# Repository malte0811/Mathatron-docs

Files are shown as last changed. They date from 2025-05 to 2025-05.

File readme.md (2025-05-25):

# The Mathatronics Mathatron calculator

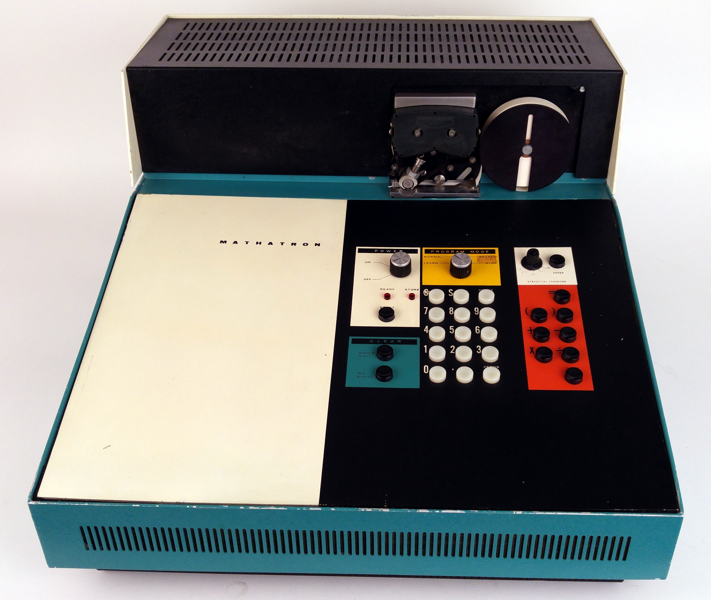
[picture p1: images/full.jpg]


The Mathatronics Mathatron calculator was the first programmable desk calculator, and also one of the first solid state
desk calculators[^1]. First sold in 1963, it was introduced just two years after the Anita Mk 7/8, the first
all-electronic desk calculator. The Anita was essentially an electronic implementation of a comptometer with automatic
multiplication and division. Compared to this, the Mathatron represents a major step forward: It allows expressions to
be entered using standard mathematical notation, including parenthesis, and evaluates them automatically, respecting
operator precedence[^2]. Programs could consist of 24 steps and use 4 number registers (in the original Mathatron 4-24),
and up to 48 steps and 8 registers in the later 4-48 model. Numbers were stored in a (binary-coded decimal!) floating
point format, with 8-9 significant decimal digits in the mantissa.

The history of Mathatronics and the development of the Mathatron calculator has been described in more detail in
multiple places, for example [here](https://www.oldcalculatormuseum.com/c-math8-48m.html) and
[here](http://calcmuseum.classiccmp.org//Mathatron_main.htm). On the other hand, very little technical information is
available: Except for some [patents](./patents.md), the only contemporary sources are some news articles and
advertisements, and I have not been able to find any existing attempt at reverse engineering at least parts of the
machine.

### This repository

In April 2024, I got access to the Mathatron 8-48 owned by the [Arithmeum](https://www.arithmeum.uni-bonn.de/) in
Bonn[^3]. Originally, this was an attempt to get it back to working order. After it slowly became clear that this was
not feasible, I decided to collect my notes in a form that may be useful to owners of other Mathatron calculators. While
some of the information is very technical and unlikely to be of interest to anyone without a Mathatron machine, much of
it is also of general interest as an example of the "lost" ideas used in machines of this era. For example, the [main
memory](./memory.md) consists of a type of magnetic core shift register[^4] that has (to my knowledge) not been used in
any other machines.

Disclaimer: While the Mathatron used in the creation of this repository is owned by the Arithmeum, the Arithmeum has had
no control over the contents of this repository.

### The Mathatron at the Arithmeum

The machine I used for this repository was acquired by the Arithmeum in an auction in 2017. The previous owner had
already done some restorations/repairs on it, for example replacing the main filter capacitors. In some cases, it is not
clear when a repair/change was done, the main reason they stand out as repairs is the newer style of resistor used. The
machine was operational[^5] a few years ago, but broke down repeatedly. Previous breakdowns were apparently easily
fixable (power supply issues), but the most recent breakdown is more complex with most likely at least two faults in the
processor logic.

The machine seems to be a special model manufactured for the [United States Bureau of Medical
Services](https://en.wikipedia.org/wiki/Bureau_of_Medical_Services). Since the BMS was dissolved at the end of the year
1966, this suggests that the machine was manufactured before that date. The official Mathatron model plate has `LKS`
stamped in place of the serial number found on other machines, while the BMS inventory label carries the numbers `62537`
and `#565`. Since these do not match the format used in other Mathatron serial numbers, they are presumably BMS-internal
inventory numbers. `LKS` could either be a generic code indicating a custom-order machine without a serial number, or it
could be a description of the features of the machine. For example, `S` is the type number suffix used for machines with
prewired programs for statistical applications, which is the set of prewired programs present in this machine.

Mathatron plate                  |  BMS plate
:-------------------------------:|:-----------------------------:
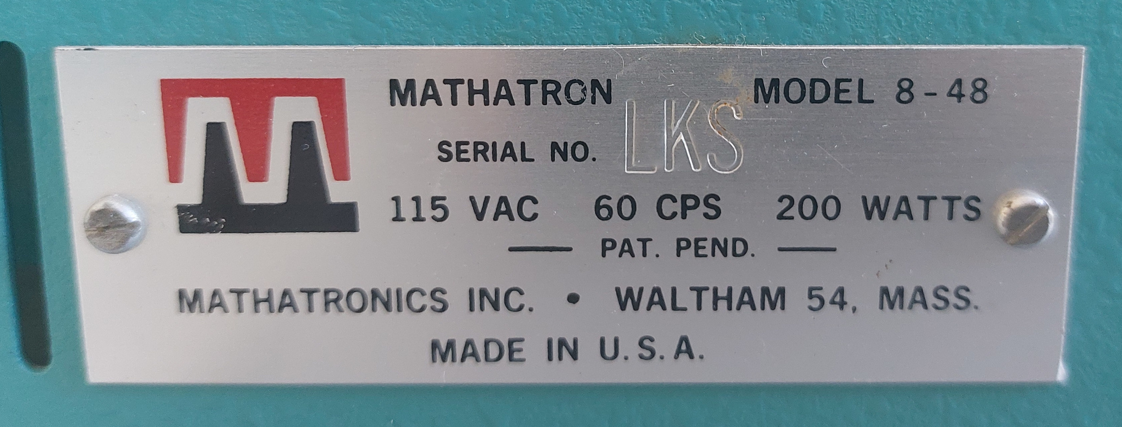
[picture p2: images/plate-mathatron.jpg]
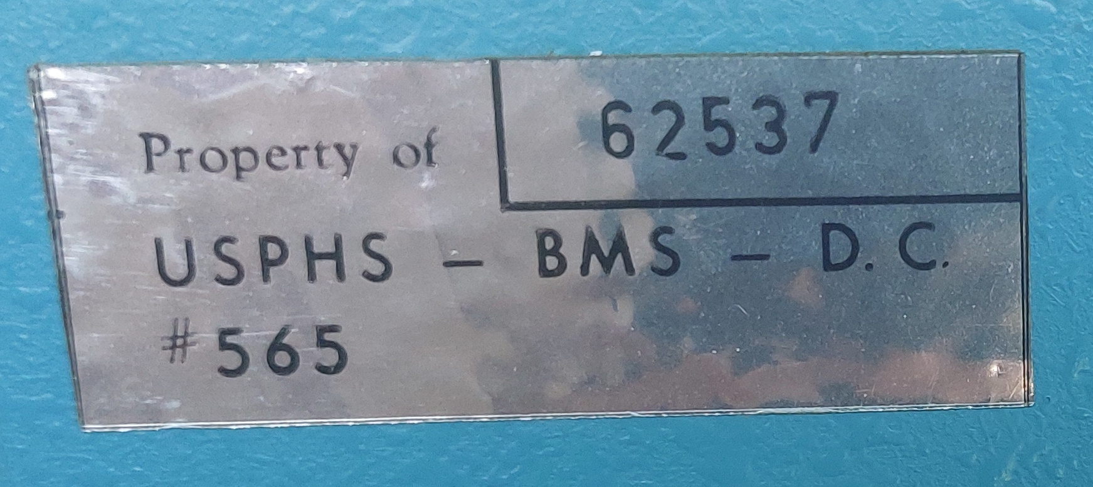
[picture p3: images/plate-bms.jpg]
|  

### Contact

If you have any additional information on the Mathatron, want to ask a question about information not covered in this
repository, or want to suggest a correction, please get in touch with me. You can either [open an
issue](https://github.com/malte0811/Mathatron-docs/issues/new) in this repository, contact me on Discord (`malte0811`),
or by email using either the address listed on my Github account or `schuerks@or.uni-bonn.de`.

[^1]: The Friden EC 130 was developed around the same time, and depending on the cutoff date (first prototype, first
    public demonstration, first sale, etc) the Friden or the Mathatron is first.
[^2]: I.e. `1 + 2 * 3` is evaluated to `7` instead of `9`. In this regard, it is more advanced than modern cheap
    calculators.
[^3]: While I am not technically employed by the Arithmeum, I work at the Research Institute of Discrete Mathematics of
    the university of Bonn, which has close ties to the Arithmeum.
[^4]: Coincident-current core memory is fairly well-known at this point, but there were many attempts of other
    topologies of magnetic core memory. The memory used in the Mathatron is only one example of these.
[^5]: In the sense of being able to evaluate simple expressions. I do not know whether parentheses were tested, and I am
    quite sure that automatic program evaluation was not tested.

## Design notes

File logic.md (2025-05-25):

#### Physical structure

The logic is distributed across 8 PCBs containing 120 PNP transistors each. 4 of these PCBs are accessible when the
machine is opened. The other 4 are installed upside-down below them, making them inaccessible without either removing
the logic unit or opening the bottom of the machine. The top boards are mechanically protected by black plastic plates,
this is not the case for the upside-down boards. The back (solder) side of the boards is accessible by removing 9 screws
on the logic unit (4 corners, 4 sides, 1 in the center).  
Each board is divided into 3 "columns" of 40 transistors each. The columns are labeled `A`-`X` on the board silkscreen.
The structure of each column is symmetric: On the outside are the 100k base bias and 2.2k collector resistors. In the
center area of a column is a matrix with one row per transistor and up to five vertically mounted resistors per row.
Sometimes, this area also contains other components, mostly ceramic capacitors. The transistors[^1] are placed between
the matric and the base/collector resistors on either side. While both the front and back of the boards look very
regular at first glance, differences from the general structure of the traces are rather common.  
The logic unit is connected to the rest of the machine by multiple plugs. 3 plugs contain the data (read/write)
connections to the [core memory](./memory.md), one connects to the keyboard (and an external control interface), and one
connects to "everything else", mostly the power supply, core drivers and printer.

Entire logic unit            |  Single board                  |Reverse side
:---------------------------:|:------------------------------:|:-----------------------------------:
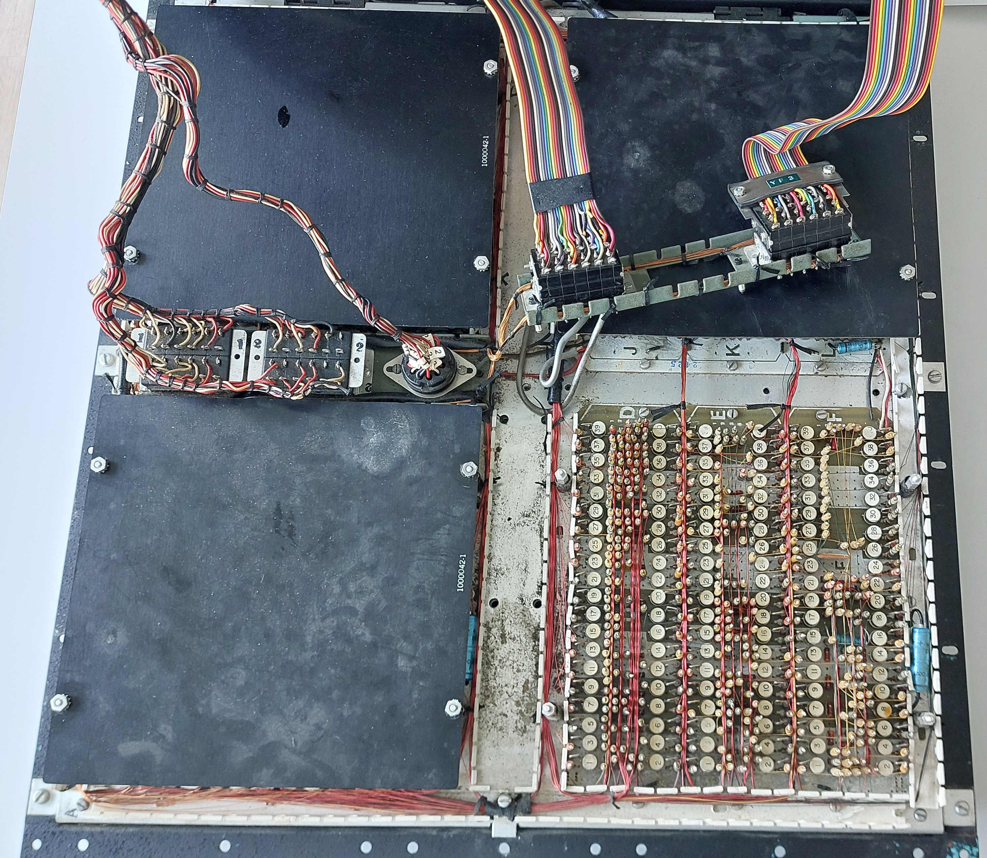
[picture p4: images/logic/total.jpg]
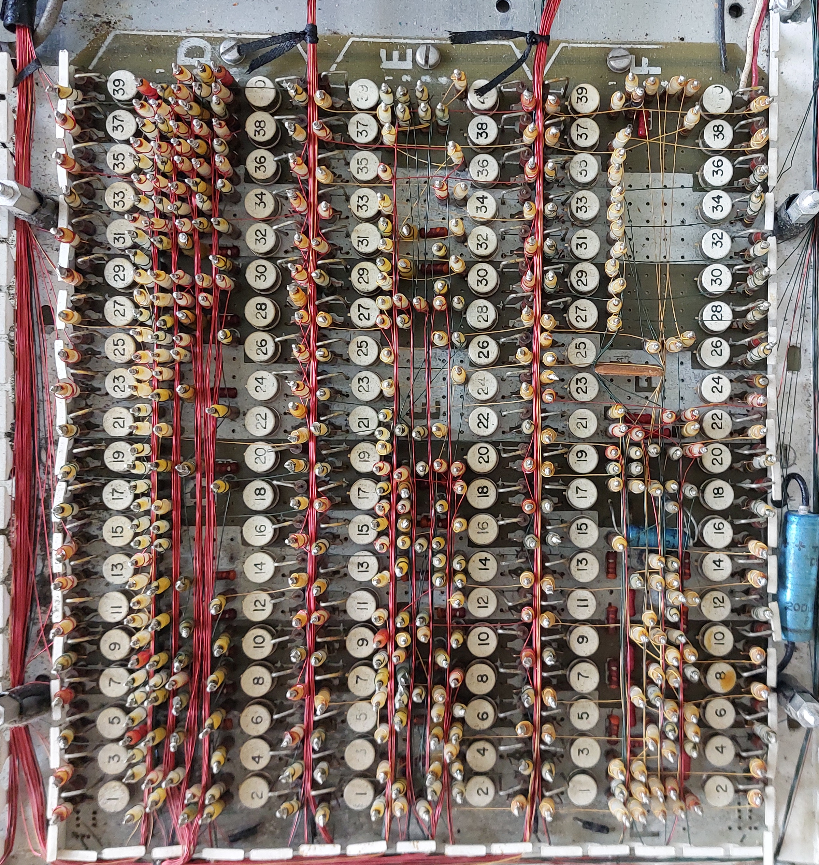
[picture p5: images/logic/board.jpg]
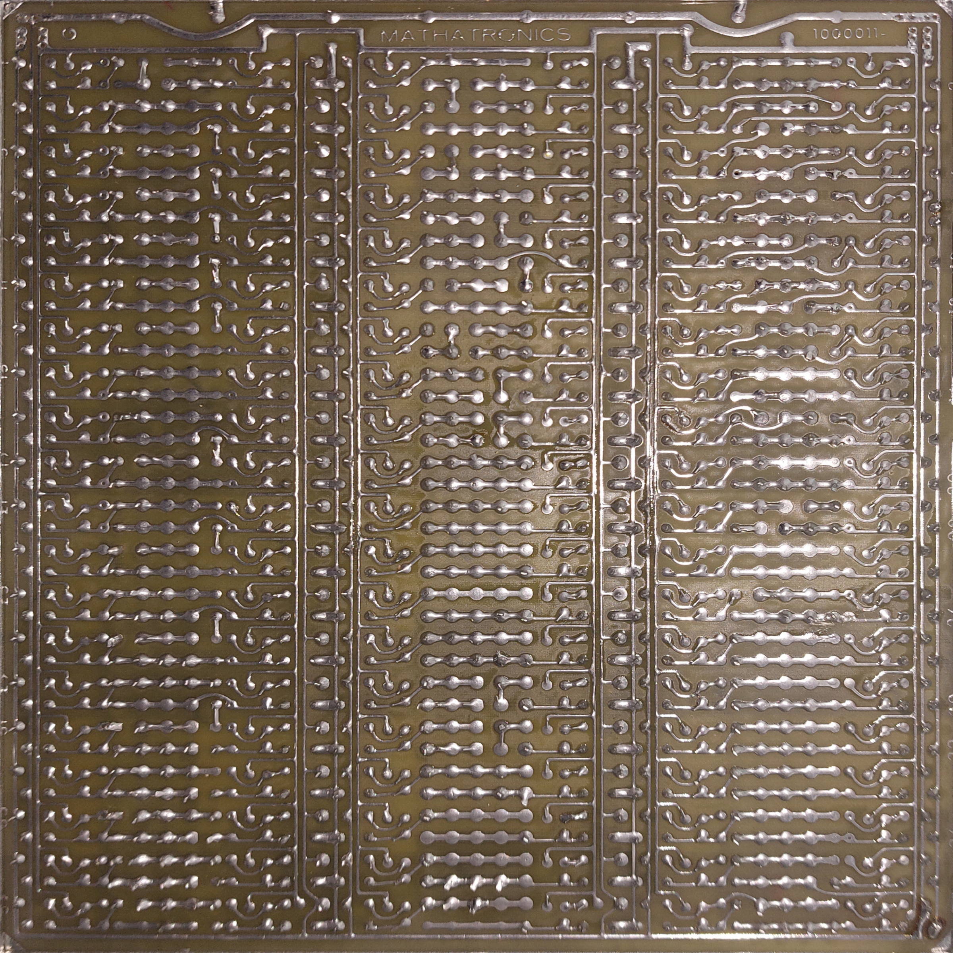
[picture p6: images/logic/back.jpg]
|   |

Only a small fraction of the connections within the logic unit is realized by traces on the PCBs. Instead, the PCBs
contain many vertically mounted resistors. The bottom terminal is connected to a trace on the PCB, while the top contact
is connected to various other similar resistors on the PCB using magnet wire. The magnet wire is connected to the
resistor using a solder joint on top of a [patented](./patents/US3502787-bobbin.pdf) bobbin. Four different colors of
magnet wire are used: "plain" copper, yellow, green, and red. It is likely that the colors have some meaning, either
indicating the type of signal (e.g. control vs data path), or the length of the connection. However, the only color
where I have found a meaning so far are the plain copper wires, which are only used for signals connecting the logic
unit to other parts of the Mathatron through plugs.

Small part of logic unit        |  Magnet wire colors
:------------------------------:|:------------------------------:
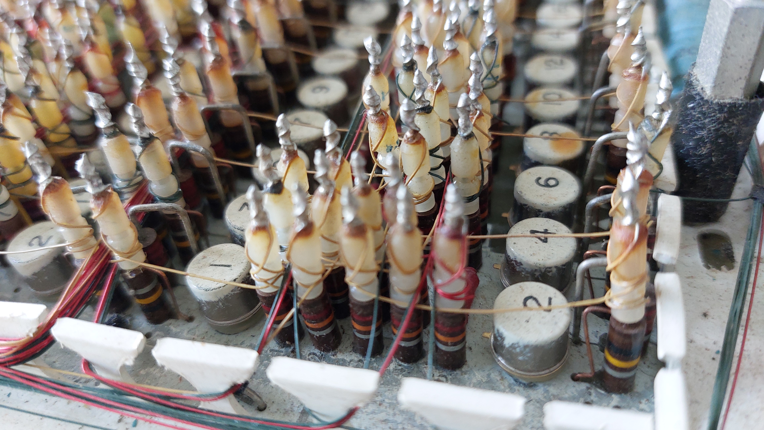
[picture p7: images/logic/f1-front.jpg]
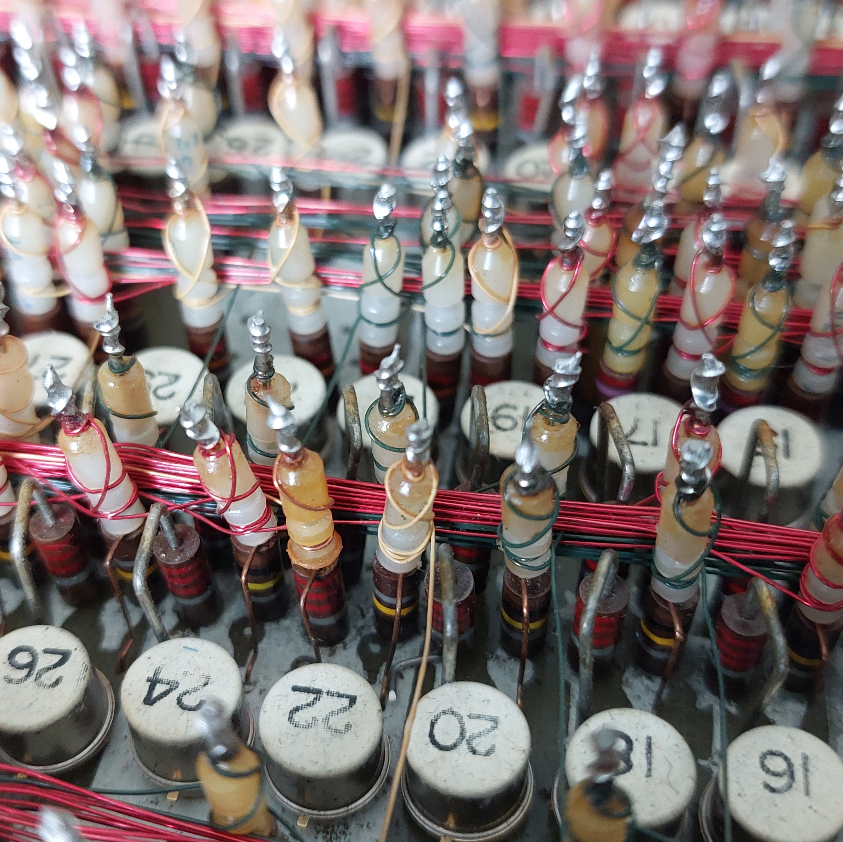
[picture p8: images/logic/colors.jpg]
|   

#### Circuit structure

The logic is primarily constructed from NOR gates, following the schematic below:



Unfortunately, in the physical construction the components of such a NOR gate are not located together. Instead, each
row contains the output stage (100k resistor and everything right of it) of one gate and the input resistors of the
following gates:



This makes it essentially impossible to reliably find all inputs of a gate: The `INT` signals are realized by magnet
wire and essentially impossible to follow. It is not even easily possible to determine whether one has found all input
signals of a gate. Another consequence is that the magnet wire does not contain a signal with sensible logic levels.
Instead, logic signals need to be probed directly at the collector resistor of Q1.

The picture below shows the numbering scheme I use for locations in the logic unit, which probably mostly matches the
one historically used by Mathatronics. The labels always refer to the signal on the top contact of the corresponding
resistor. The base of transistor `T` and the output of the corresponding NOR gate are referred to as `T.B` and `T.C`
(collector). The input resistors of the "next" NOR gate are labeled `T.1` to `T.5`, some of which might not be present.
If some of them are not populated, the indices follow the grid, e.g. only `T.1` and `T.4` might exist for some
transistors. When the column is clear from the context, `T` is simply the painted number on the transistor (`14.3`),
otherwise the column letter is included as a prefix (`F14.3`).

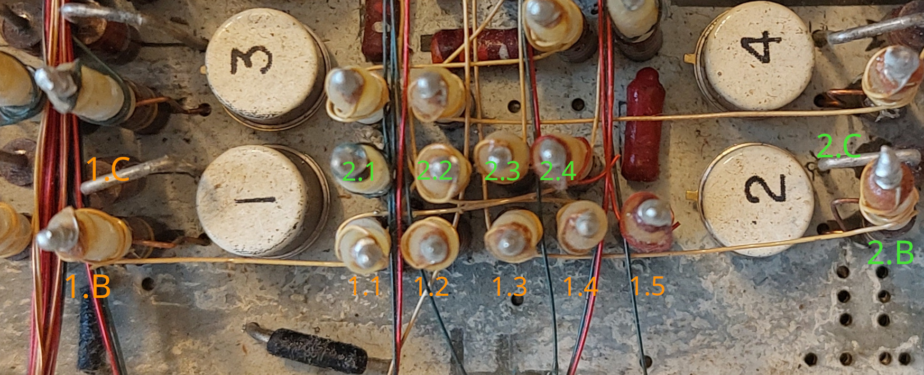
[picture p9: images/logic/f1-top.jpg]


In some cases, the structure deviates from that described above. The simplest deviation is an "AC-coupled input" to a
NOR gate, i.e. an input that is `1` briefly when the previous stage switches from `0` to `1`. This is used e.g. in
counters/T-flip-flops.

#### Reverse engineering

Tracing the magnet wire connections visually (as usually done on PCBs) is essentially impossible for anything more
complex than very short local connections. Instead, everything has to be traced using continuity testing. Continuity
testing runs into two issues.

The first is that the solder joints on top of the resistors are typically sufficiently corroded so that standard
multimeter probes do not make contact. Placing probes on opposite sides of the same joint often does not show
continuity, and applying additional pressure to pierce through the oxide layer with probes is not possible due to the
mechanical construction. The most practical alternative I have found is to always use aligator clips to contact the
solder joints. This is much slower than a quick touch with a multimeter probe, but works very reliably while minimizing
the risk of mechanical damage to the circuit.

The second problem is more interesting: Which connections should be checked for continuity? For those parts of the
boards following the standard row/NOR layout, there is a good answer: The top contact of a "center" resistor should be
connected to exactly one base resistor. Most connections are likely to be "short"/"local", so it is reasonable to start
by looking for connections within a column. This can be done in 1-2 hours per column by checking for continuity from
each "center" resistor to each base connection using the same wire color in the same column. This information can then
be used, together with any "special" PCB structures in the column, to obtain an incomplete list of inputs to each NOR
gate, and a list of outputs to unknown other gates. It is also possible to generate a SPICE netlist to verify
behavior.  
For some columns, e.g. [column `F`](./printer-logic.md), this is enough to follow most of the logic. For other columns,
e.g. `D` and `E`, it does not give much useful information. These columns contain many rows not following the usual
structure, and also many NOR gates with (presumably) inputs from other columns. They also do not contain any connections
to known external signals[^2]. I have not found a reasonable way to trace these inter-column connections yet. I also do
not know how to trace efficiently trace connections in areas that do not follow the usual row structure, and therefore
are not necessarily connected to a base resistor.

#### Utilities and files

The data for the columns I have measured and some utility scripts can be found in [`logic-data`](./logic-data). The
scripts operate on the data for a single columns, which is a directory with the following files. `column-f` is the most
complete example of these files.
- `nets.txt`: This encodes the main connectivity information. Each line has the form `<dotname> <base>`. `dotname` is a
    reference to one of the resistors in the "grid" of the column (e.g. `14.4`). `base` is the index of the BJT to whose
    base this signal is connected (e.g. `3`). For grid positions where a resistor is present, but the base it connects
    to is unknown, `base` is replaced by `?<color>`, e.g. `?green`. The color refers to the magnet wire connected to the
    resistor. If no resistor is present in a grid position, the line is omitted from the file.
- `names.txt`: This files indicates known names for signals, for easier analysis. Each line has the form `<id>=<name>`.
    E.g. `13=bit4` indicates that the collector signal of transistor 13 should be called `bit4`.
- `special-ccs.txt`: This file encodes regions where the traces on the circuit board deviate from the usual row pattern.
    Each row specifies to one connected component, by listing all grid positions that are part of this component as a
    space-separated list. If the last entry of this list is a grid position, the name for the connected component will
    be generated automatically. If the name has the form `base(i)`, the grid positions will be considered as connected
    to the base of transistor `i`. Otherwise, the last entry will be used as the name for the component directly.
- `components.json`: This file lists any additional components placed in the column (primarily capacitors). The file
    should be an array of JSON objects, each of which encodes one "type" of component (e.g. 33 nF capacitors). These
    objects should contain 3 entries:
  - `namePrefix`: The name for the components will be this string followed by an index. This also indicates the
      component type to SPICE.
  - `connections`: An array of array of strings. Each entry of the outer array lists the pin positions of one "instance"
      of the component type, using grid position notation.
  - `lineSuffix`: Any additional information that should be added to the line in a SPICE file. E.g. the capacitence
      value of a capacitor.

[^1]: All transistors are  germanium PNP transistors. The exact transistor model may have varied between different
    Mathatron machines: Some sources, both contemporary and modern, claim that 2N404 were used. On the other hand, both
    the Arithmeum machine and the machine shown
    [here](https://neuron.eng.wayne.edu/auth/Calculators/Mathatron%208-48%20Hassoun/) use Texas Instruments GA2464
    transistors, for which I have not been able to find a datasheet.
[^2]: Column `F` connects to the [printer position sensor](./printer.md), which gives a clear entry point for
    understanding the purpose of the logic.

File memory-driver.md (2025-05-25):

The core drivers can be divided into roughly 3 sections: Those at a positive voltage relative to the core windings
("top"), those at a negative voltage relative to them ("bottom"), and the parts that cross from top to bottom. These
include the core windings themselves, but also some other "side" circuits. The most positive voltage is around 40V,
while the most negative is -10V. At a high level, the top section connects the correct drive lines to +40V. The other
end of the drive lines are connected to one of three constant current sinks in the bottom section, one for the main
drive and one for each of the two copies of the auxiliary driver. The additional side circuits ensure that the current
is at the drive current even between pulses, presumably to reduce supply voltage variation.

### Top side

The top side is formed by the "15-BJT-board" (see [construction](./construction.md)). The top row of PNP BJTs (2N1906)
select the main drive line, while the lower two rows (2N1905) correspond to the two copies of the auxiliary driver[^1].
In addition to the BJTs, there are various components mounted on the back of the board, as well as 10 small pulse
transformers in the bottom edge of the board. The 3 transistors arranged as a column correspond to the same "phase" of
the core driver. The first pulse is in the rightmost column, then the columns are activated one by one from left to
right.  
A pulse on one of the five shift lines is triggered by pulling a logic-level input (0 to -10V) low for 10µs, the
duration of a pulse on the main driver. The logic input is connected to the base of the corresponding main drive PNP
through a 1µF electrolytic capacitor, used to obtain a pulse relative to the 40V emitter voltage instead of 0V. Before
the collector wire enters the memory core, it passes through four pulse transformers at the edge of the board (single
turn each). Two of these cause the corresponding auxiliary drive transistors to turn on. After about 6 µs, the cores of
these transformers saturate, ending the auxiliary pulses[^2]. The windings in the other two transformers (the ones used
to drive BJTs during the previous pulse) are polarized such that they do not turn on the connected PNP transistors, they
only serve to reset the magnetization state of the cores. The order of the transformers along the board edge matches the
BJT columns.  
Some of the auxiliary drive transistors have a low-value resistor (3.9 Ohms in parallel with 6.81 Ohms) connected in
series with the drive transformer. There does not seem to be a pattern to which of them have the resistor and which ones
do not. I suspect that the resistor is supposed to be present for either all of them or one of the two rows, but that
this was accidentally changed in an earlier attempted repair on the Arithmeum machine: Some of these precisely-chosen
resistors are connected between DC rails, and they use a newer style of resistor than the rest of the machine.

Front                        |  Back                         |Transformers
:---------------------------:|:-----------------------------:|:-----------------------------------:
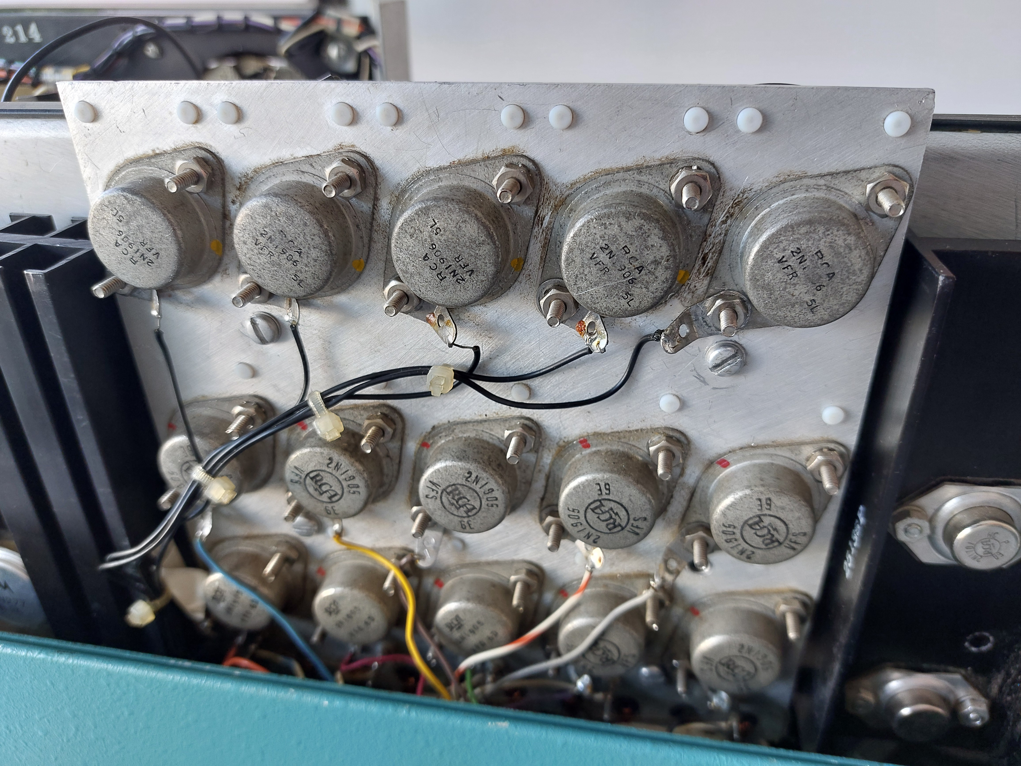
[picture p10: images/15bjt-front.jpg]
|   |

### Bottom side

The bottom side of each of the three drivers (one main, two auxiliary) consists of a simple switched current sink as
shown below. Before the start of an operation (i.e. after a button is pressed), `Enable` switches from -10V to 0V. The
voltage at the upper end of the resistor will be roughly one diode drop below 0V, essentially independent of the voltage
at the input (collector of Q1). This results in a roughly constant current through the resistor, and hence also a
constant current at the input.  
For the two auxiliary drivers, Q1 is one of the 2N1701 (smaller package) on the right heatsink. The current setting
resistors are in the top left corner of the "mixed board" and consist of a 15 Ohm resistor in parallel with another
resistor. In the Arithmeum machine this additional resistor is 91 Ohm for one driver and 68 Ohm for the other, so this
was probably used to fine-tune each of the drivers.  
The current sink for the main driver is also split across two transistors and setting resistors, probably due to the
high total current required (1.5A). These are the larger 2N2338 on the same heatsink. The setting resistors are the
variable resistors at the back of the resistor cage. For these current sinks, the base voltage (`Enable`) is not driven
to 0V but to the voltage of the "extra cap cable" (see [power supply section](./power-supply.md)). This corresponds to
roughly -4V, but uses some variety of active regulation.



### Side load

To keep the supply voltage stable, the current draw should be as constant as possible throughout the memory cycle. For
the main driver this is generally fulfilled automatically since the pulse on one phase ends when the pulse on the next
phase starts. For the auxiliary drivers, where the pulses are shorter, this is implemented explicitly using the circuit
below: `Q17` and `I2` represent the current path through the actual core memory, `I1` is the current sink described
above.  
During a memory current pulse, `Q17` is saturated, pulling `Vcenter` close to +40V. As a result, the emitter voltage of
`Q16` is positive and, since the base is connected to ground, no current flows in this path. Since the maximum
emitter-to-base voltage for `2N3053` is 5V, `D6` is used to take up most of the voltage drop[^3].  
Outside of a memory pulse, the current through `Q17` is zero. As a result, `Vcenter` moves to roughly -1.4V,
corresponding to the diode drops across the base/emitter junction of `Q16` and `D6`. The current path is now through
`R24`, `Q16` and `D6`. Most of the voltage drop is across `R24`, a power resistor found in the "resistor cage".



[^1]:  The common datasheet for both transitors can be found
    [here](https://w140.com/tekwiki/images/1/1e/Rca_2n1905_datasheet.pdf).
[^2]: This also implies that modifying the drive current of the main driver will change the pulse duration of the
    auxiliary driver, since the cores will saturate earlier/later.
[^3]: The actual emitter voltage of `Q16` will be determined by the reverse leakages of `D6` and the base/emitter
    junction of `Q16`. The resulting voltage is likely either beyond the 5V rating or very close to it, causing these
    transistors to fail. In the Arithmeum machine, this transistor had failed in both copies of the circuit, though with
    different symptoms.

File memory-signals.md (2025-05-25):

This sections describes the data connections to the core memory. The read and write circuits seem to match those in [the
patent](./patents/US3438011-shift-register.pdf): The write circuit discharges a small capacitor (50 nF) through the
coil, the read circuit consists of an impedance matching stage followed by a simple RS-latch. The RS-latch is somewhat
biased towards the input from the core since this has a lower signal level than a general logic pulse. Some (all?) of
the write circuits are located in column A, the read circuits are likely located on the lower boards.

Write circuit:  
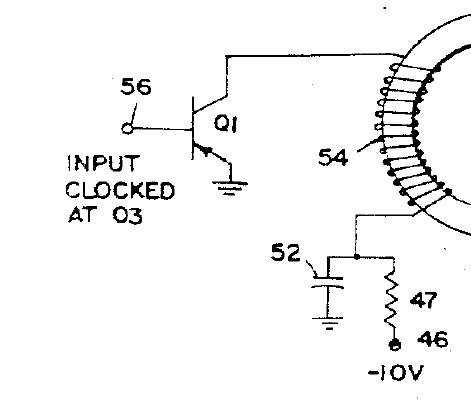
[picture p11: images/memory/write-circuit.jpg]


Read circuit:  
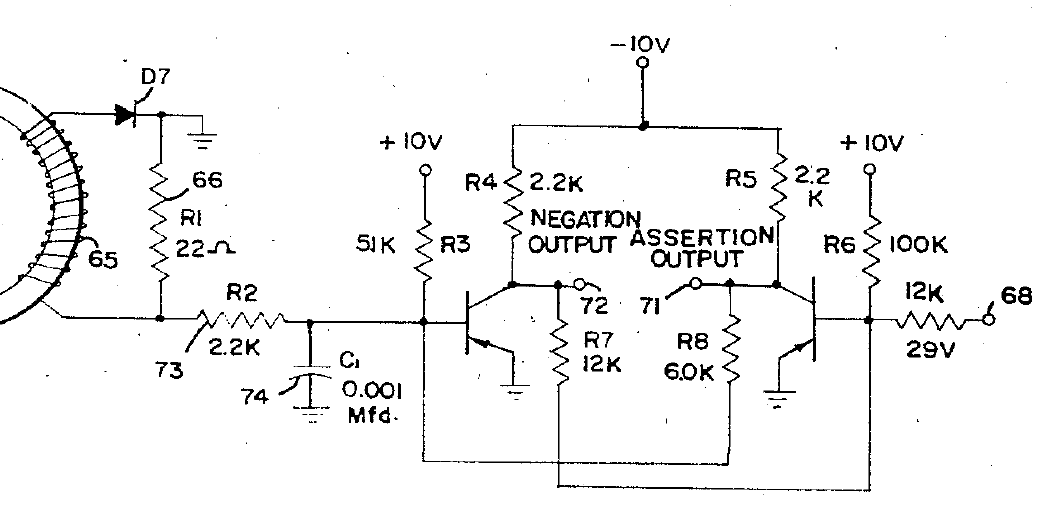
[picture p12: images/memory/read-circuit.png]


#### Connection to the processor

The connectors from the processor to the memory are located on the left half of the logic unit. In the Arithmeum
machine, there are three connectors in total: Two "rectangular" connectors labeled "1" and "2", and an additional "tube
socket" type connector. Most wires on these connectors are red or white, with a few additional black wires.  
The general convention on the rectangular connectors seems to be that black wires are only used for ground connections.
Red wires carry signals coming from the memory (read), and white wires carry signals from the processor to the memory
(write). This also makes sense as an easy-to-remember mnemonic: *red* is *read*, *white* is *write*. There are a few
exceptions to this rule, as some white wires also carry power signals to the "memory interface board". The rectangular
connectors contain a total of 18 red and 20 white wires. Two of the white wires are placed "apart from the rest" and
carry power connections. While the program storage register is logically a 192-bit register, it is most likely
implemented as 4 separate 48-bit registers. This would ensure that shifting all registers 48 times does not affect
memory content. Under this assumption, the 18 read/write pairs correspond exactly to the 14 data registers (A, B, R1-R4,
S1-S8) plus the 4 sub-registers of the program storage register.  
The single black wire on the tube socket also seems to be a ground connection. However, the other wires are most likely
all read connections despite alternating between red and white: There are only 18 capacitors for generating write pulses
on the memory interface board. Additionally, adding additional write points to the memory would be a complex task. On
the other hand, adding additional read points to the memory is simple since the read circuit (without the 22R loading
resistor) presents a high impedence. It would be very hard to implement the algorithms used by the Mathatron without
additional read points, especially 4 bits from the end of the A, B, and R1 registers: These registers are combined
arithmetically, so the processor needs to read a full 4-bit digit from them before having to write the "new" version of
the same digit. The algorithms also make use of shifts to the right, which again require access to the second-to-last
digit.

#### Probing

Both read and write signals can be easily probed on the rectangular connectors. For write signals (white wires), the
"default state" is -10 V, with exponentially decaying pulses to 0V on a timescale of about 10 µs. I am not sure at this
point whether these pulses correspond to logical 1s or logical 0s in the register. A logic analyzer with a threshold of
-5 V gives reasonably clean signals. Read signals (red wires) have much lower signal levels, but can also be probed
without any special considerations on signal integrity: Unlike traditional core memory, this style of core memory
provides a multi-100mV pulse on read outputs.

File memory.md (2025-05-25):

> This section describes the high-level operation of the memory. Details on the main and auxiliary pulse drivers are
> described in the section on [memory drivers](./memory-driver.md), while details of the memory data connections can
> be found under [memory signals](./memory-signals.md).

The Mathatron uses an unusual type of core memory as its main memory described in US patent US3438011: The cores are
used to implement a shift register, or rather multiple shift registers. Data is still stored by the core magnetization
state at one bit per core, but some additional cores are needed to handle the shifting. Additionally, the cores are much
larger than in typical (coincident-current) core memory, with an outer diameter of 6-7 mm. The shift register is divided
into segments of `n` cores along its length (`n=5` for the Mathatron). At all times one of the `n` cores in each segment
is "empty" in the sense that its magnetization state is not part of the memory content. The position of this empty core
is the same in each segment at the same time, and its state always corresponds to a logical 0. A drive "phase" consists
of moving the content of the core before the empty core into the empty core in each segment. After `n` phases, a single
bit is extracted from the shift register.

The picture below shows a 12-bit shift register, using 5 phases like the Mathatron memory. Data is fed into the register
on the left, and read from it on the right. The cores are colored by their phase. At the start, all cores except for the
blue ones contain data bits (letters). A single drive phase moves the contents of the red cores into the blue ones, now
leaving the red cores empty. In the next phase, data is shifted from the yellow cores to the red ones. This phase is
special because the first core of the shift register is red, and the last core is yellow. The contents of the first core
are simply cleared, leaving it available for data to be written to it in one of the following phases[^1]. The contents
of the last core are transfered into a read circuit (essentially a flip-flop), which makes the data bit `M` available to
the processor. After three more drive phases, the last row of the image shows the register in the same state as at the
start, but with all bits shifted by one position to the right.



The shifting is implemented by passing a current through windings[^2] on both the core being shifted from and the core
being shifted into (the "empty" core) at the same time. The pulse through the core being shifted from is known as the
"main" pulse, while the pulse through the core being shifted into is known as the "auxiliary" pulse. Both pulses are
strong enough to flip the magnetic state of the cores, but the auxiliary pulse is only "barely" strong enough. To pass
information from the first core to the second, there is a 5-turn "output winding" on the first core connected to a
single-turn "input winding" on the second core. If the first core flips, a current pulse is induced in the output
winding and through that in the input winding. This pulse is opposed to the auxiliary pulse and it strong enough to
prevent the second core from flipping. If the first core does not flip, no current is induced and the second core flips
from the auxiliary pulse.

To prevent a flip of the second core (in the next phase) from flipping the first core through this output/input winding,
the windings are connected by a diode. The voltage induced in the single-turn input coil by a flip of the second core is
smaller than the forward voltage of the diode, so cannot affect the first core.

The polarity of the main pulse corresponds to setting a core to 0. Since the auxiliary pulse needs to flip the
previously empty (hence logical 0) core if not opposed by the input/output pulse, its polarity sets cores to 1. This
implies that shifting involves an inversion: If the core being shifted from was previously set to 0, it does not flip,
no current is induced, and the empty core is set to 1. If the core being shifted from was previously set to 1, it flips,
induces a current, and prevents the empty core from flipping from its 0 state. For simplicity, this is ignored in the
image above.

In some cases, it is necessary for the logic to have access to the "next" digit in memory: If e.g. two numbers are
added, their last decimal digit would normally shift out of the core memory (bit by bit) during the same period as the
last digit of the result is shifted into the core memory. Since the digits need to be fully known to compute the bits of
the result, this would not be possible with "pure" shift registers. Instead, an additional output measurement coil is
installed on the core 4 bits (5 cores) from the usual output core. This provides the "next" digit to the processor,
allowing it to compute (in the example) the summed digit before it has to entered into memory. In some cases, some cores
are physically missing from a register, presumably for similar reasons.

### Physical construction

The memory is divided into rows of 20 cores each, using the wiring scheme suggested in figure 10 in the patent. Each row
is manufactured as a separate module. In the Mathatron 8-48 at the Arithmeum, there are approximately 40 modules in the
larger section on the back (only partially accessible) and 12 modules in the smaller section at the front. Since the
shift register uses 5 cores for 4 stored bits, each row corresponds to 16 bits and each 48 bit register consists of 3
rows.

The drive wires are threaded through the entire core, with the starting point at the top of the front core section.
Below the core sections, the wires simply pass from each core "column" of the front section into the corresponding
column in the back section. At the top of the back section, the wires are threaded back into the corresponding column of
the next section of the module. Since the direction of the drive wires reverses between sections, the polarity of the
input/output windings of the modules also reverses at each section boundary.

The auxiliary drive is split into two identical copies of the same driver circuit for unknown reasons. The first two
segments of each module are driven by one of these, the remaining two segments are driven by the other. The main drive
is not split in this manner, and drives all segments of all modules.

The main and auxiliary driver circuits are reasonably accessible and described in [this section](./memory-driver.md).
Unfortunately, the data in- and output circuits and especially their connections to the core are not. This makes the
organization of the memory into logical registers a guess. The front section is likely the program storage for both
pre-wired and user-provided programs (see below). The back section probably consists of either 39 or 42 modules,
corresponding to 13 or 14 48-bit registers. This roughly matches the patent: 8 S-registers for user programs, 4
R-registers for handling parathesis, and A and B registers for intermediate results. This corresponds to 14 registers
overall. On the right end, a wire connects the last contacts of every third row. This contact probably corresponds to
the last (or possibly first) bit of a register, where data is inserted/extracted.

Missing cores                        |  Register connections                    |
:-----------------------------------:|:----------------------------------------:|
|   |

#### Pre-wired programs

Mathatron provided multiple "pre-wired" programs with each machine, which allowed common programs to be entered with a
single keypress. This is probably achieved by threading one wire per pre-wired program through the entire program
storage. When a current pulse is applied to this wire, all cores of the program storage are simultaneously set to the
correct value for the respective pre-wired program. I have not been able to confirm this directly, but there are
strong arguments in favor of this theory:
- There is no "large" memory in the machine besides the main core memory (no core rope or similar). The pre-wired
    programs have to be stored somewhere, and a wire passing through all relevant cores provides this storage in a
    cheap and compact form.
- Storing and entering the pre-wired programs in this manner minimizes the amount of extra circuitry needed to support
    them: Entering a program means sending a single current pulse through a wire not used for any other purpose, while
    executing a pre-wired program is indistinguishable from executing a user-provided program and therefore does not
    need any extra hardware. The program selection knob seems to directly select between such wires. The actual
    processor does not have to be modified in any way to support pre-wired programs.
- The front section of the memory has a large amount of "random" thin wires going through it. I do not have access to
    the reverse of the back section of the memory, but the "randomness" of these wires suggests that they may be used to
    implement the programs. Additionally, the memory of the front section (12 rows of 16 bits) corresponds exactly to
    the 192 bits needed to store 48 4-bit program steps.
- The wiring of the selector and the ENTER button for pre-wired programs: The ENTER button is a SPDT switch, that
    normally charges a small electrolytic capacitor (connected to the common contact) through a resistor. When pressed,
    this capacitor is connected to "some wires in the core" through the program selector.
- There is some suggestion that the front section of the memory can be replaced with relatively little work, which
    matches the fact that Mathatronics offered to install pre-wired programs in existing machines.
- The main Mathatron patent (US3996562) mentions that the pre-wired programs (in particular the square root program) are
    stored in the same memory as the user program.

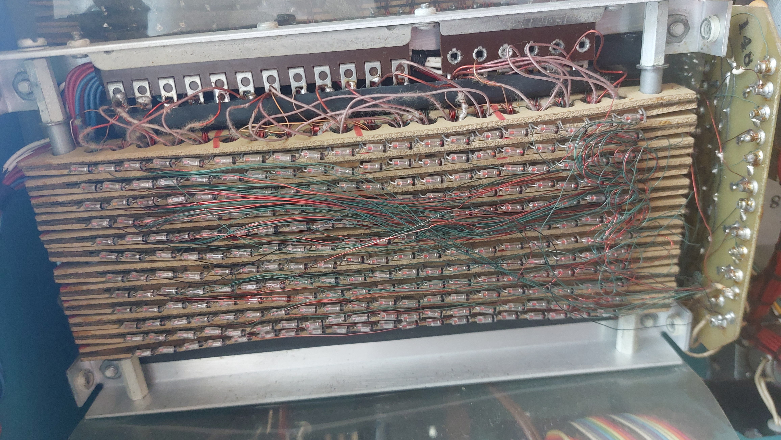
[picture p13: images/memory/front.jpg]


[^1]: It does not matter during which phase the input is written to the core, as long as it happens before the next
    phase shifting from red to blue.
[^2]: These are single-turn windings, using a wire passing straight through all cores of a phase.

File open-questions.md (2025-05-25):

This list contains some strange details I found and was unable to explain, as well as general questions about the
history of Mathatron machines.
- Two parallel resistors in the "resistor cage" dissipate 20W each, for 40W total. There is no forced-air cooling in
    this area, and even without the cover attached the resistors reach 80°C (176°F) within 20 seconds. Both the
    temperature and the total wasted power would suggest that this is not the intended behavior. On the other hand, the
    resistors are Ohmite power resistors rated for operation up to 350°C, so it may be the correct behavior after all.
    There is also another resistor in the resistor cage dissipating multiple Watts, but nowhere near as much as this
    pair.
- Is the -10V rail intended to be at that voltage? In the Arithmeum machine, it seems to be too close to 10V to be
    caused by broken regulation. On the other hand, this would mean that the main logic levels of the machine are -10V
    and 0V. Both the [main Mathatron patent](./patents/US4611307-mathatron-latest.pdf) and some documentation[^1]
    suggest that it should be -5V and 0V.
- What is the correct value, and the purpose, of the large resistor on top of the resistor cage? In the Arithmeum
    machine this is a fixed-value dark green resistor without any markings. In measurements, it shows a very low value,
    but this could also be some other circuitry in parallel with the resistor. In pictures of other machines, this
    resistor seems to be adjustable rather than fixed-value.
- On the right side of the "mixed board", a white/purple striped wire leaves the board and enters a wire harness, only
    to leave the harness a few centimeters later and connect to the board again. The endpoints of the wire are already
    connected by a trace on the board. Was this intended to confuse reverse engineering efforts, or spot direct clones?
    Or is it an artifact from an earlier revision of the machine?
- What is the correct wiring behind the 15-BJT board? In the Arithmeum machine, it appears that this section has been
    modified in some earlier attempted repair/restauration (newer resistor style). Some high-precision resistors are
    placed between DC signals that are also connected by far lower-precision resistors, while some base connections are
    missing series resistors. It seems likely that this was a mistake during the earlier changes.
- The Mathatron at the Arithmeum seems to be a custom model, probably similar to IBMs "Request Price Quotation". How
    does it differ from a normal 8-48S, which seems to be what the customizations are based on?
- What is the full model history of the Mathatron calculator? For example, the [machine owned by Mohamad H.
    Hassoun](./known-machines.md) looks identical to the Arithmeum machine on the outside, but uses a different layout
    of the logic unit and contains an additional board in the top section.

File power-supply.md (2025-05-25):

#### Filter capacitors

The filter capacitors have been replaced in the Arithmeum machine, so this information should be taken with a grain of
salt.  
The left set of capacitors consists of 1000µF capacitors, while the right section uses 3300µF capacitors. With the
exception of the top right capacitor of the left section, all center connections are to ground.

##### Connections in the left section

-45V (A): Used for the printer, rectified by two diodes on the mixed board.

-45V (B): Used for BJT base bias, rectified by a single diode on the mixed board.

+45V (A): Directly after half-wave rectification, not used for anything

+45V (B): After smoothing by a large inductor (transformer-like, inside the main chassis), forming a pi-network with the
capacitors for +45V (A).

+10V: This is primarily used for base bias in the main logic unit. It seems to be derived from +40V (B) by a dropping
resistor, without any regulation.

-10V: This is derived using some sort of regulation from the -18V rails in the right capacitor section. The positive
(inner) end of one of these capacitors is not connected to ground, but to a different net referred to as the "extra cap
cable" in some schematics.



##### Connections in the right section

TODO work out A vs B

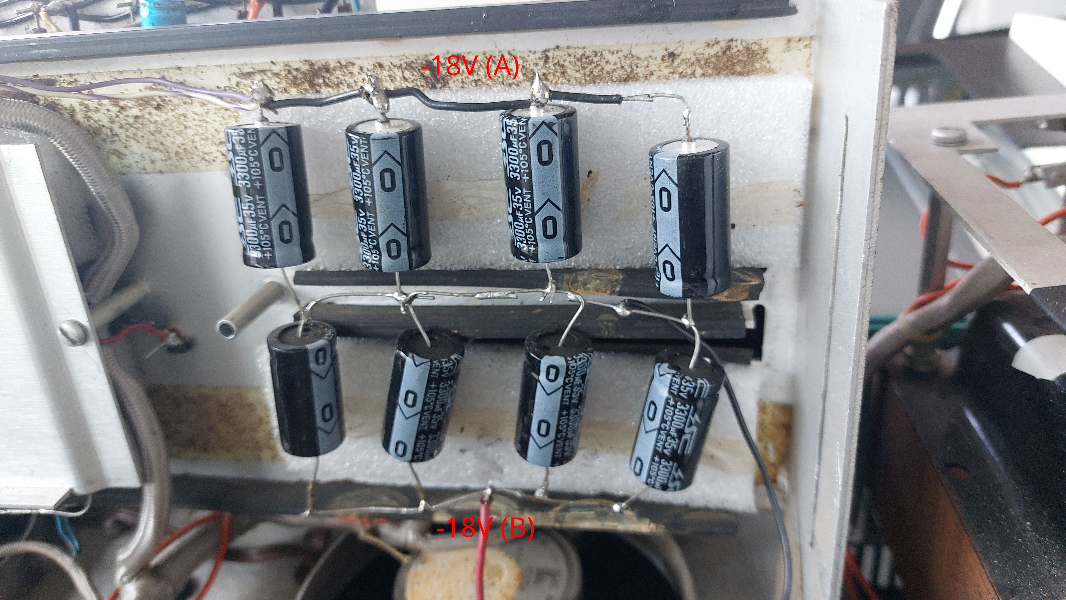
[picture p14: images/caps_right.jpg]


#### Other circuits

The higher-current rails are rectified using stud-mounted diodes in front of the "mixed board". The lower-current rails
use generic axial-lead diodes mounted on the mixed board itself. There are two additional high-power (stud-mounted)
diodes on the mixed board itself. In the Arithmeum machine one of them is mounted on a heatsink, but this appears to be
a late modification: [This](http://www.calcuseum.com/SCRAPBOOK/BITMAP/BONUS/75987/_SMD75990_XL.htm) picture shows the
internals of the same machine before it was acquired by the Arithmeum. The right stud-mounted diode is still mounted
directly to the board, but the board is already discolored around it (indicating high power dissipation). This is
confusing since, from my measurements, this diode should only conduct when the +10V rail drops below 0V. At the same
time, this seems to be a realistic scenario since the original design included a high-power diode. The other high-power
diode prevents the "extra cap cable" from becoming more negative than the -10V rail.

One of the more confusing parts of the Mathatron is (what I assume to be) the regulation circuit of the -10V rail. This
is the main voltage used in the logic unit, so it is at the same time a high-current supply and needs to be reasonably
stable under uneven current (processor activity). However, the regulator "feeds" the -10V rail depending on the voltage
of the "extra cap cable", and tends to reduce the current when the voltage drops rather than increasing it (both in
simulation and measurements). The circuit can be found in the `PSU` sheet of the KiCAD project in the `schematics`
folder. As usual, since this is based on reverse engineering, it is likely to contain mistakes.

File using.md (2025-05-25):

> This section is not based on reverse engineered data from the machine at the Arithmeum, instead it is essentially a
> summary of parts of US patent 4611307.

#### General operation

To use a Mathatron as a basic calculcator, the `PROGRAM MODE` switch has to be set to `NORMAL`[^1]. After turning the
main power switch to `ON`, the `START` key has to be used to prepare the machine for operation. This causes the `READY`
light to come on. After this, the machine can be operated using "normal" (infix) mathematical expressions, e.g. `12 + 17
/  4`. All entered numbers and operators are printed to the paper tape. After each keypress, the `READY` light should
briefly go out before coming back on[^2]. Pressing `=` prints the result of the expression and returns the machine to
"standby" mode (i.e. `START` has to be pressed before the next computation).

- Opening brackets at the start and closing brackets at the end of the expression can be ommited.
- The `ZEROS` button allows the user to use scientific notation: Entering a number `a`, pressing `ZEROS` and entering a
    number `b` corresponds to entering the number `a * 10^b`[^3].

The 8 data registers[^4] are referred to as `S1` to `S8`. To store a value in one of them, enter the value (or a formula
computing the value) and press the `=S` key, followed by the index of the data register. The `STORE` light will come on
while the Mathatron waits for the register index to be entered[^5]. After this, the value can be used in computations by
entering `S` followed by the register index at any point inside the formula. The register contents can also be printed
using `PRINT` followed by the register index.

#### Programming

The Mathatron is programmed by selecting the `LEARN` mode and entering a sequence of equations. These equations will
typically use the `S`-registers for intermediate results and possibly some inputs. To run the program, the `AUTO` button
is used in one of the other modes (`NORMAL`, `BRANCH`, `STOP`). The Mathatron will then essentially simulate the same
sequence of keystrokes used to create the program.  
Every time a constant[^6] is encountered, the program is interrupted and the user is asked to input the correct
value[^7]. This makes programming for "simple" repetitive tasks very intuitive: To compute e.g. the same expression for
every row of a table, it is enough to enter the expression once for the first row while in `LEARN` mode. Afterwards, it
is enough to enter the contents of the table into the calculator, treating `AUTO` as a "next field" key.  The behavior
upon reaching the end of the entered program depends on the selected mode:
1. In `NORMAL` mode, the program continues from the start as an infinite loop.
2. In `STOP` mode, the program will stop after a single execution. It may be necessary to press the `AUTO` button once
   for every unused program step (of 24 or 48) to return to the start of the program, but this may be a mistake in the
   patent.
3. In `BRANCH` mode, the program will be repeated if the last result computed before the end of the program was
   negative. This is primarily intended for iterative numerical methods (e.g. Newton's method), where the last result
   might indicate whether the remaining error is below some set threshold. In this application, no values are entered
   into the program. The `BRANCH` mode can also be used to accumulate some expression over an arbitrary number of input
   values, e.g. computing $\sum_{i = 0}^n x_i^2$.

#### Prewired programs

Each Mathatron calculator comes with a number of "pre-wired" programs. These are commonly used programs that can be used
at the push of a button. The most common example (present in all machines?) is the square-root program, approximating
the square root of the value in register `S1` and storing the result in `S3`. Other programs are available depending on
the type of Mathatron, e.g. `8-48S` machines contain pre-wired programs for various statistical functions. These
pre-wired programs are entered into the same program storage used for user programs. This has two direct consequences
that may not be obvious from general information on the Mathatron:
- Using a pre-wired program automatically erases the current user program.
- Pre-wired programs (including the square-root function) cannot be used as steps in user programs.

#### A note on Turing completeness

It is not entirely clear whether the Mathatron (in `BRANCH` mode) should be considered Turing complete. This question is
of interest since Turing completeness is often a consideration when deciding whether a device should be considered a
computer or a calculator. Clearly, the computation model needs to be generalized to provide arbitrary amounts of memory.
Since there is no indirect addressing, this has to be done by making the memory available in each register infinite
instead of providing an infinite number of registers. There are (at least) two somewhat natural ways to generalize the
floating point values stored in the registers:
1. Registers store rational numbers.
2. Registers store a product of an integer with a power of 10. Here, the exponent cannot be an arbitrary integer, since
   e.g. division by 3 would not have a well-defined result. Instead, the exponent has to have a fixed minimum value.

Intuitively, the important difference between these two approaches is that the second allows access to individual digits
of an integer value `a`: For example, the last (least significant) digit can be accessed using `a - (a / 10^(e - 1)) *
10^(e - 1)`, where `e` is the minimum value of the implicit exponent. The second part of the formula can be interpreted
as shifting `a` to the right and then back such that the least significant digit cannot be expressed in the intermediate
result. This allows a register to be used as an infinite stack (or one side of the tape of a turing machine).

See [On the control power of integer division](https://www.sciencedirect.com/science/article/pii/0304397583901299) for a
full proof that the second model is Turing complete, noting that this number model is equivalent to integers. I am not
aware of a proof that the first model is not Turing complete. Some results from the same paper suggest that it is not,
but they only apply to numbers that can appear as intermediate results after a fixed number of iterations. These values
*can* be computed as the final program output (after a non-constant number of iterations), so this is not enough to
prove incompleteness.

[^1]: `BRANCH` and `STOP` are likely to work as well, but this has not been tested and is not specified in the patent.
[^2]: The `READY` light is extinguished during processor activity. This can cause confusion since there is no external
    way to distinguish between operation and "standby" (`START` not pressed/computation completed).
[^3]: If the patent is accurate, negative values of `b` are not supported.
[^4]: Or 4 in a Mathatron 4-24
[^5]: This light bulb is missing in the Bonn machine, it is not clear when it was removed.
[^6]: A constant is defined as a numerical constant followed by an operator. It is not clear whether `=S` is considered
    an operator in this context.
[^7]: For more complex programs, this is of course a problematic behavior: Such programs are likely to contain constants
    that are not supposed to be modified (e.g. π). The documentation stores these "global" constants in register before
    the program is started, which still seems cumbersome and error-prone.

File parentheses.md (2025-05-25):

> This section is not based on reverse engineered data from the machine at the Arithmeum, instead it is essentially a
> summary of the patent US 4611307.

One of the main selling points of the Mathatron was its capability to handle parentheses in a mathematically correct
manner. The algorithm used for this is probably best explained by starting with an example without any parentheses. When
moving through the computation from left to right, the result can always be stored in the form `X + Y * current_number`,
where `+` may be replaced by `-` and `*` may be replaced by `/`.

|Entered formula |`12`|`*` |`2` |`+` |`18`|`/` |`3` |`-` |`7` |`*` |`4` |
|---|----|----|----|----|----|----|----|----|----|----|----|
|`X` | | | |`24`|`24`|`24`|`24`|`30`|`30`|`30`|`30`|
|`+` or `-` | | | |`+` |`+` |`+` |`+` |`-` |`-` |`-` |`-` |
|`Y` | |`12`|`12`| | |`18`|`18`| | |`7` |`7` |
|`*` or `/` | |`*` |`*` | | |`/` |`/` | | |`*` |`*` |
|`current_number`|`12`| |`2` | |`18`| |`3` | |`7` | |`4` |

The final result can easily be evaluated from the last column by first combining `Y` and `current_number` according to
the multiplication-type operator (`*`) and then combining the result with `X` according to the addition-type operator
(`-`):
```
X - Y * current_number = 30 - 7 * 4 = 30 - 28 = 2
```

To handle parentheses, we can add a stack that stores the values of `X` and `Y` (and the operators) for the part of the
formula before the parenthesis. The value inside the parentheses can then be evaluated as above when the parenthesis is
closed. The resulting value is stored as the `current_number` and the `X` and `Y` values present before the opening
parenthesis are restored from the stack. The state of all registers is now as if the value of the parentheses had been
entered as a number manually.

In the Mathatron, `X` corresponds to `R2`, `Y` corresponds to `R1`, and `current_number` corresponds to buffer register
`B`. The multiplication-type operator is stored as the operation attached to `R1`, while the addition-type operation is
attached to `R2`. Shifting is performed by moving each register `Rn` to register `Rn+2`. This process is described in
more detail in figure 4 of the patent. Empty values in the example computation above are replaced by special "identity"
codes in the Mathatron, which does not affect a value it is combined with.

Since only `R1` to `R4` exist, it seems like the Mathatron can only handle one level of parentheses [^1]. The example
computation performed in columns 16 and 17 of the patent also suggest this, since it uses all 4 registers to handle a
single level of parentheses. However, this is contradicted by the first paragraph of column 10 of the patent, which
claims that one level of parentheses can be handled using just `R1` and `R2`, while two levels can be handled using `R1`
to `R4`. Until this can be tested on a working machine, I would give more weight to the example computation and assume
that only a single level of parentheses can be handled by the hardware. Obviously, the algorithm works for arbitrary
levels of parentheses, so supporting more levels would "only" mean adding registers. It is not clear whether the machine
supports the use of two levels if one of them is the "top level": The expression `(1 + 2 * (3 + 4)) / 5` contains two
levels of parentheses in the first part, but at no point are there more than two levels with non-identity values.

[^1]: I.e. `1 + 2 * (3 + 4 * 5)` can be computed, but `1 + 2 * (3 + 4 * (5 + 6 * 7))` cannot.

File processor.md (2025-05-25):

> This section is not based on reverse engineered data from the machine at the Arithmeum, instead it is essentially a
> summary of the patent US 4611307.

The Mathatron is a [serial computer](https://en.wikipedia.org/wiki/Serial_computer), processing one 4-bit digit at a
time. This allows the processor to work on 48-bit registers with much fewer transistors than one might expect from
modern machines: The processor only has to be aware of its current position within the register and to be able to
perform basic digit-wise operations. Therefore, the transistor count depends (mostly) logarithmically on the register
size, rather than the linear or often super-linear dependence found in modern processors. On the other hand, processing
time is linear in the size of the registers: Only a single digit is processed in each "processor cycle". The serial
nature of the processor also explains the choice of shift registers for the main memory: they form the "natural" data
storage for a serial processor, presenting data in the digit-by-digit form required by serial processors.

The control logic of the processor is organized as a state machine[^1]. Each state is kept for 96 1-bit memory pulses,
i.e. each register is fully shifted through twice in each state. Confusingly, according to the patent the switch between
states ocurs at memory pulse 72, i.e. half-way through the second "pass" of the registers. Figures 8-10 in the patent
show the state sequences for various operations. The index of the state is shown in the top left of each box, while the
circled numbers describe the various "subcommands" controlling the datapath of the processor during this state. These
subcommands can describe direct "actions" (e.g. 51="Print the + character"), but can also describe the "routing" of
information within the processor (e.g. 6="transfer adder output to exponent position of buffer"). All subcommands are
described in the list starting in column 18 of the patent.

### Floating point handling

The state machine diagrams shown in the various subfigures of figure 8 are relatively basic, describing short, fixed
sequences of states. The diagrams in figures 7, 9 and 10 are more interesting. Figure 7 is essentially a formal
description of the [parenthesis handling](./parentheses.md). I have not analyzed figure 10 (describing printing and
single-digit deletion) yet, as it seems to contain some errors and undocumented signals. Figure 9 describes the logic
used to perform a single arithmetic operation on the floating point registers.

TODO describe and include annotated version of figure 9

According to the patent, the worst-case time for a single operation is 125 "cycles" of 96 memory pulses lasting 75µs
each, i.e. nearly a full second. I have not worked out the example for which this worst-case runtime ocurs, it should be
something along the lines of a multiplication/division involving 99...99.

[^1]: The states are referred to as "cycles" in the patent. I will use the modern term "state" in this explanation.

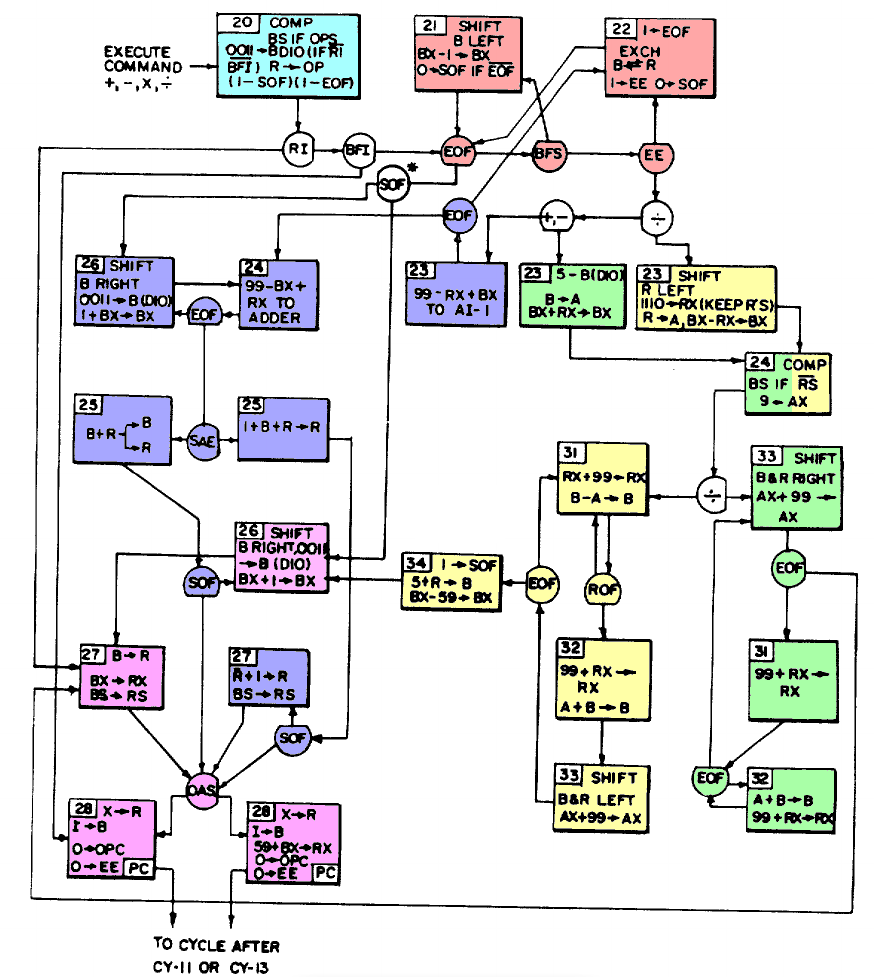
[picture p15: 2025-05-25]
images/arithmetic_sections.png

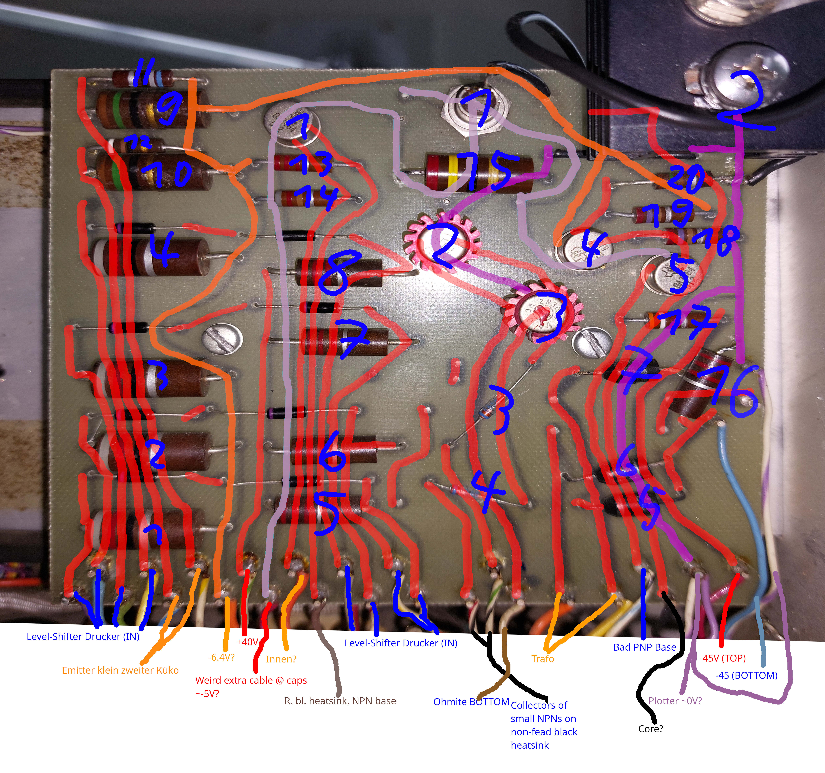
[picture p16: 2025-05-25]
images/mixed-board-annotated.jpg

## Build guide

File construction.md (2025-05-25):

The internal construction of the Mathatron is divided into two sections. The top part of the case behind the printer
assembly contains the power supply, the core drivers, and some circuitry related to the printer. The interior of the
main part of the machine contains the keyboard circuitry, the core memory itself, and the main logic.

### Top section

The top cover can be removed without any tools by carefully pulling it straight up. It is only held in place by friction
in a groove around the back and sides of the case. Below is a list of the main areas of the top section, with the
"nicknames" for them that I use throughout the rest of the documentation:
1. Resistor cage: This is a collection of power resistors. Some are used in the general power supply, while others are
   used in the core driver. This area is separated from the rest of the top section by a sheet in the top cover.
   I suspect that this is meant to avoid heating other components (including the filter capacitors), but it also means
   that the resistors are separated from the airflow of the fans. In the Arithmeum machine, some of the resistors
   dissipate a rather large amount of power (2 are dissipating 20W each!), and therefore get very hot quickly. It is not
   clear whether this is a problem with that particular machine or intended, the resistors are rated for 350°C.
2. Printer assembly: This is a very self-contained assembly, see [printer section](./printer.md) for details. It can
   easily be removed by removing two screws connecting the assembly to the main case and unplugging it.
3. Filter capacitors: These capacitors have been replaced by the previous owner of this machine, but I assume that the
   structure matches that used by the original capacitors. There are two rows of capacitors stacked on top of each
   other, with nearly all "center" contacts connected to ground. For details and the exception to this rule check the
   [power supply section](./power-supply.md).
4. Mixed board: This printed circuit board contains various "miscellaneous" circuits, both to adapt logic signals to
   drive e.g. the printer, and lower-power parts of the power supply and core driver. One of the two power diodes is
   mounted on a heatsink in the Arithmeum machine, this appears to be a quite recent modification. There is a burn mark
   at the original mounting point of the diode, I assume that it grew hot due to some other fault. See
   [here](./mixed-board.md) for a complete schematic of the board.
5. 15-BJT board: The board is not a printed circuit board, more of a combination between heatsink and mechanical
   support. The BJTs form part of the core driver and are described in the relevant part of the documentation. In the
   Arithmeum machine, the board is held by 4 screws, 3 of which are easily accessible. The remaining screw is located
   below the top lid of the case, so it cannot be reached with a screwdriver. I usually leave this screw loose enough to
   unscrew by hand.
6. Left (black) heatsink: This contains a Darlington-pair arrangement of two transistors and seems to be part of the
   power supply.
7. Right (black) heatsink: This heatsink has two pairs of BJTs that are used to form current sinks for the core drivers.

Front                        |  Back                         |Cover
:---------------------------:|:-----------------------------:|:-----------------------------------:
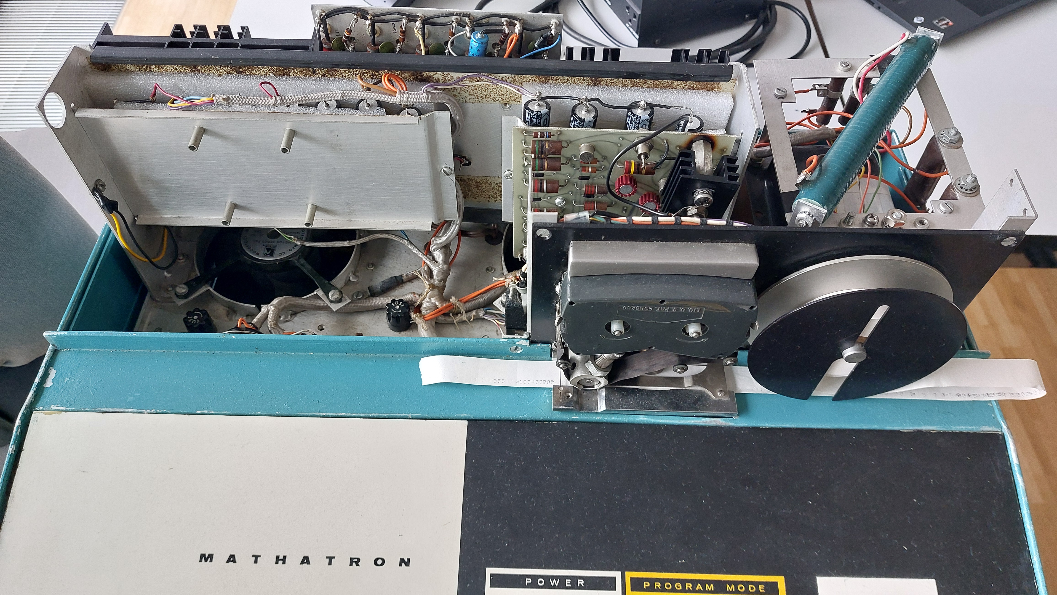
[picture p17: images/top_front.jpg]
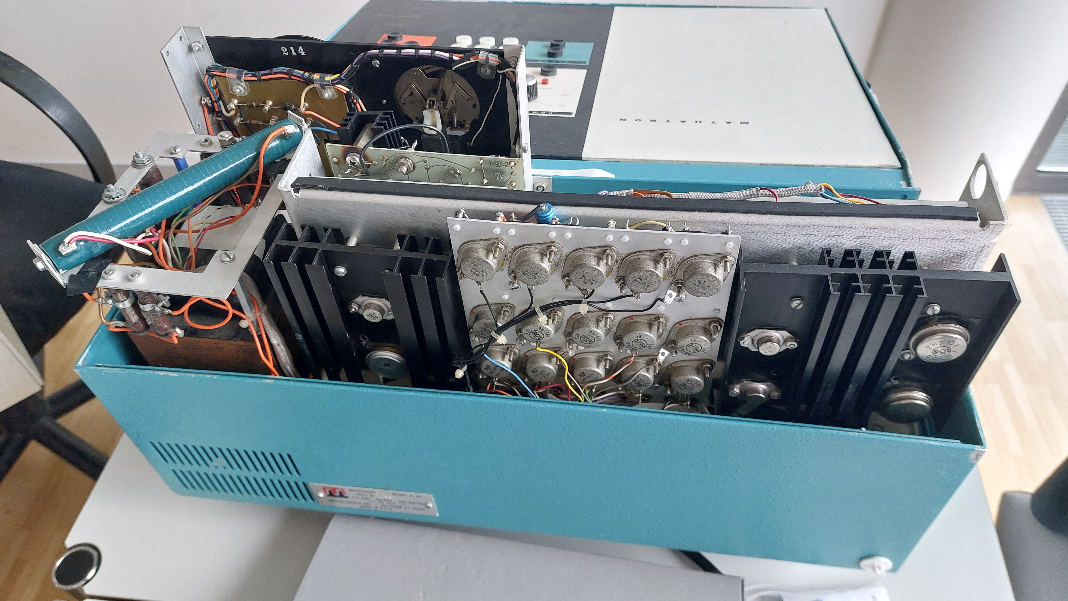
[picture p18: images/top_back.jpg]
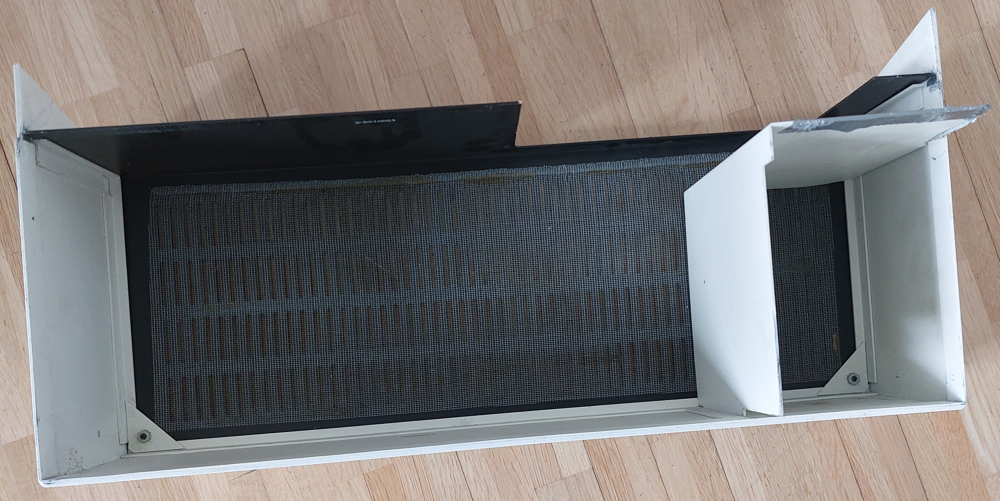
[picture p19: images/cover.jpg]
|   |

### Bottom section

The main part of the Mathatron can be opened in two ways: First, it is possible to lift only the top plate. The core
memory and the keyboard logic are mounted on the back of this. Second, the entire top part of the case can be opened on
hinges at the back. In both cases, there are various wire harnesses that can get stuck when either opening or closing
the cover[^1].  
In both cases, the hex screw below the front of the machine is essential. This screw passes through holes in the bottom
part of the case, the top part of the case, and the top plate (or rather a small assembly connected to it), with the
latter two holes being threaded. To lift the top plate, the screw needs to be unscrewed enough to be out of the last of
these holes. At that point, the top plate is free to be lifted. The easiest way to lift it for the first few centimeters
is to simply push it up by the same hex screw.  
To open the entire top section of the case, unscrew the same screw entirely. Additionally, 16 screws have to be removed
around the bottom of the machine. Afterwards, the top section can be lifted at the front. For stability, it can be a
good idea to reinsert the hex screw between the top section of the case and the top plate.

The main parts of the bottom section are the following:

1. Core memory (A): See [section on memory](./memory.md)
2. Logic assembly (B): There are 8 square logic boards, 4 visible in the picture and another 4 on the bottom of the
   assembly. The assembly can be lifted by removing the screws connecting it to the bottom part of the case[^2]. To
   access the back of the boards, the screws in the corners, the "edge-centers" and the center of the assembly have to
   be removed. Afterwards, the assembly opens with the hinge at the back. See [here](./logic.md) for some limited
   information on the logic.
3. Keyboard assembly: The keys and status lights are controlled by a separate circuit board. The board mainly encodes
   the per-switch signals to a 5-6 bit vector used by the main logic assembly. The circuit board is mounted on hinges,
   after removing two screws it can be lifted to access the actual keys.
4. Memory interface circuitry: This board seems to be responsible for handling most non-drive signals connected to the
   core. Its position between the core memory and the keyboard assembly, combined with the fragile wires connecting it
   to the core memory, make it hard to analyze this board. Some information can be found in the [memory
   signal](./memory-signals.md) section, but this is based on generalizing the structure of one somewhat accessible
   section.

Mains voltage is present inside the machine, but only in a very limited area. The main shock hazard is the solder strip
towards the back of the machine, which has some contacts connected directly to the mains. The main power switch is
connected to this strip by isolated cables, so the keyboard is generally a safe area. The internal power supply is
galvanically isolated from the mains (L/N), but uses the PE conductor as its 0V potential. The supply voltages include
-40V and +40V, so it is not necessarily safe to touch non-mains voltages within the machine.

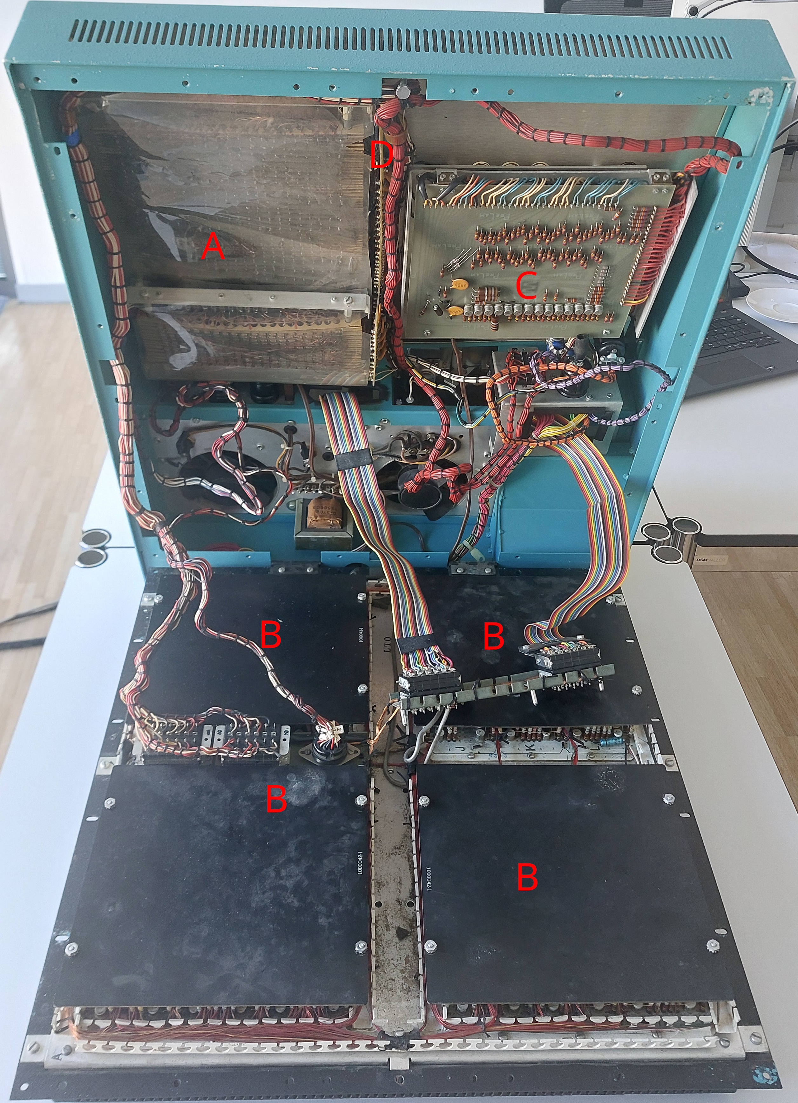
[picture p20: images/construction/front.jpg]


[^1]: In the Arithmeum machine, the most problematic of these harnesses is one that gets stuck under the cover plate of
    the front right logic board when opening the entire top of the case. This happens very early while opening the
    machine (few cm of gap), so you usually do not see the harness when you need to remove it.  
    Additionally, the wire connecting the logic unit to the top section is rather short. The connector has to be lifted
    up before the top cover can be fully opened. This happens much later in the opening process, so you can easily see
    what is happening.
[^2]: Be very careful when doing this. The logic unit is relatively heavy and has to be placed back with good precision
    to avoid damage to the exposed circuitry of the bottom boards.

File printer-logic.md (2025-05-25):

The printer logic is currently the only section of the logic that I have traced out (see [logic](./logic.md) for details
on the technique used). In the machine at the Arithmeum, this logic is located in the rightmost column (F) of the upper
front right processor PCB. The easiest way to check whether this is the same on another machine is to check whether the
base of transistor 39 is connected to one of the pins of the printer position sensor (see [printer
section](./printer.md)). Additionally, there should be 12 small ceramic capacitors between transistors 1-14, an
electrolytic capacitor inside the logic around transistor 17, and only a single collector resistor for each of the
transistors 27-37.

Transistors 1-14 form a 5-bit counter, indicating the current position of the 20-character type wheel. The first stage
is implemented as a standard RS latch consisting of two NOR gates (one transistor each), while the later stages use
T-flip-flops: The base of a "propagation" transistor is connected to the inverted output of the previous stage through a
capacitor (red, dog-bone type). This produces a pulse whenever the previous stage switches from logical 1 to logical 0
(inverted output: 0 to 1, i.e. 0V to -10V). This pulse is connected to the bases of both transistors in a (TODO name of
this). This counter is fairly sensitive to the values of the capacitors used for both propagation and within the stages,
similar to mechanical calculators with an "instantaneous" carry mechanism.

The 5 outputs bits of the counter are then fed into a comparator. The other input represents the character to be
printed, i.e. the print buffer. When both inputs are identical, the printer hammer is triggered. The comparator circuit
uses a total of 13 transistors, nearly a third of the column (two per bit and three extra to collect the results). For
each input bit, the circuit computes `Ac NOR !Ap` and `!Ac NOR Ap`, where `Ac` is the counter output bit and `Ap` is the
bit in the printer buffer. When both bits are equal, both of these expressions are zero since (exactly) one of the
inputs is 1. When the bits differ, both inputs will be 0 in one expression and both 1 in the other. The former
expression will therefore evaluate to 1. Taking the `OR` (or `NOR`) over all of these values then gives the comparison
result. Presumably due to fan-in limitations, the results of bits 0, 1 and 2 are combined first (`comp0To2`) using an
`OR` gate (`NOR` followed by `NOT`) and only then combined with the remaining results. The inverted signals do not have
to be computed explicitly, the negations of both `Ac` and `Ap` are available from the circuits providing their
non-negated values. 

The counter can be reset by one of two mechanisms. The first is the signal labeled `reset`, which is a buffered version
of the magnetic sensor in the print wheel. `bit0` is not reset by this, presumably since its state is implied by the
state of the motor. The other bits are reset to excess-3 zero, i.e. `1100`. These bits also contain the corresponding
excess-3 value when printing digits. The other reset signal is provided by transistor 26 and is currently somewhat
mysterious. Confusingly, it does not reset either `bit0` or `bit1`.

After the machine is powered on, the position of the type wheel is unknown. As a result, the counter output can only be
trusted after the first time it is reset by the magnetic sensor. This logic is not located in column `F`, and also
appears to be partially broken on the Arithmeum machine. Based on the behavior of that machine, it seems like this is
achieved by pulling all (some?) print buffer bits to `1` for a fixed period at the start of the first print cycle. Since
this is not a valid combination that will ever be reached by the counter, this prevents any printing until the wheel has
completed at least one revolution. In the Arithmeum machine, the inputs are held in this state permanently, but only
some of them. Due to this, the printer works if the first digit is 5 or more (so that the highest bit is set in
excess-3), but spins the print wheel indefinitely if the first digit is 4 or less. After this first digit, all digits
work as expected.

### Connections

This table provides the known base connections of transistors in this column. The same name is used for a transistor and
its collector signal. For signals that I do not understand yet I simply use the transistor number. The collector signal
is the logical NOR of the base signals. Due to the construction method, it is possible and often likely that some base
connections are missing. `cap(S)` indicates that the base is connected to the collector of `S` through a ceramic
capacitor, while `elcap(S)` indicates a connection through an electrolytic capacitor.

|Transistor ID|Collector signal name|Base connections (potentially incomplete) |
|---|---|---|
| 1 |bit0 |nbit0, cap(reset0) |
| 2 |nbit0 |bit0, cap(set0) |
| 3 |prop1 |cap(nbit0) |
| 4 |bit1 |prop1, nbit1, cap(nbit1), reset |
| 5 |nbit1 |prop1, bit1, cap(bit1) |
| 6 |prop2 |cap(nbit1) |
| 7 |bit2 |prop2, nbit2, 26, cap(nbit2), reset |
| 8 |nbit2 |prop2, bit2, cap(bit2) |
| 9 |prop3 |cap(nbit2) |
|10 |bit3 |prop3, nbit3, cap(nbit3) |
|11 |nbit3 |prop3, bit3, 26, cap(bit3), reset |
|12 |prop4 |cap(nbit3) |
|13 |bit4 |prop4, nbit4, cap(nbit4) |
|14 |nbit4 |prop3, bit4, 26, cap(bit4), reset |
|15 | |18, nCompAll |
|16 | |15 |
|17 | | |
|18 | |elcap(17) |
|19 |nCompAll |compNBit3, compBit3, compNBit4, compBit4, comp0To2 |
|20 | | |
|21 |reset0 |18 |
|22 |set0 |18 |
|23 | |reset0, set0 |
|24 | |nbit0, reset0, set0 |
|25 | |bit0, nbit1, nbit2, bit3, bit4, 18 |
|26 | |cap(25) |
|27 |compBit0 |bit0 |
|28 |compNBit0 |nbit0 |
|29 |compNBit1 |nbit1 |
|30 |compBit1 |bit1 |
|31 |compNBit2 |nbit2 |
|32 |compBit2 |bit2 |
|33 |compNBit3 |nbit3 |
|34 |compBit3 |bit3 |
|35 |compNBit4 |nbit4 |
|36 |compBit4 |bit4 |
|37 |nComp0To2 |compBit0, compNBit0, compNBit1, compBit1, compNBit2, compBit2 |
|38 |comp0To2 |nComp0To2 |
|39 |nSensor |[to printer sensor] |
|40 |reset |nSensor |

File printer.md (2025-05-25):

The printer unit is described at a high level in patent [US3304858](./patents/US3304858-printer.pdf). The printer is
built as a very independent unit and can easily be removed: First remove the top cover of the Mathatron. Unplug the
printer unit (one plug, just left of the printer) and remove the two screws at the front attaching it to the blue
chassis. The printer can then simply be lifted out of the machine. Running the machine with the printer unit removed
will not work well even for measurements, since it will try to align the print wheel when the first digit is entered.

## Operation





The printer consists of a type wheel (A) with 20 positions. The position of the wheel is controlled by a stepper motor
(E). Printing is achieved by a hammer (B) below the paper pushing it against the type wheel, with the ink ribbon in
between. After printing, both the tape and the ribbon are advanced by a common solenoid (F). Additionally, the printer
contains a magnetic sensor (C) to detect the position of the print wheel.

Usually, the tape is held quite tightly between two rollers. To manually pull out the tape, use lever (D) to release
the lower roller. This can also be used to pull back the tape during testing, or to feed a new tape into the printer.

## Electronics

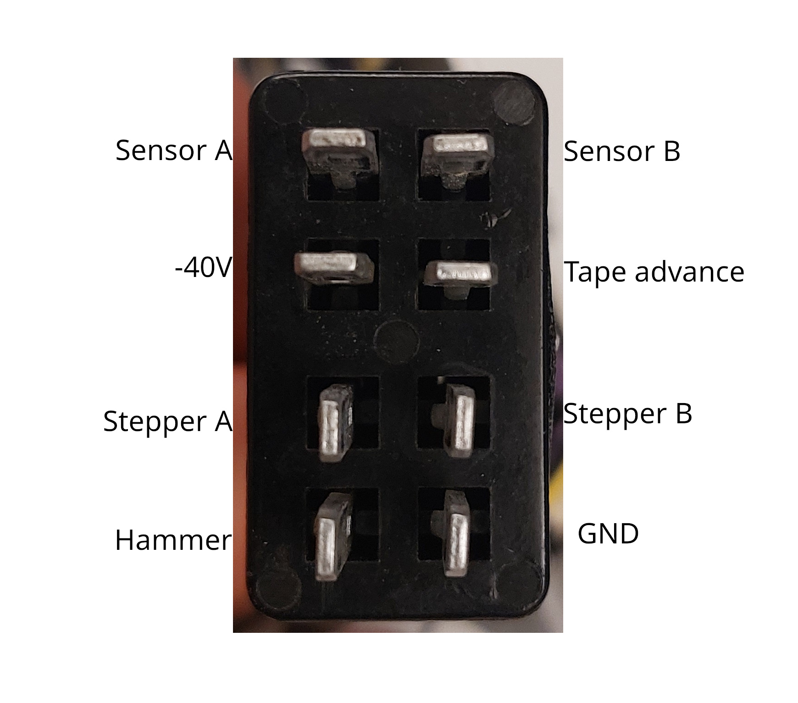
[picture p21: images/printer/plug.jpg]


Above is the pinout of the plug connecting the printer to the main unit. The control signals to the printer are
connected directly to the base of one of the 2N1540/1541 transistors (Germanium PNP). They are connected to the actual
logic input through a diode, with a pullup to +40V. The pullup and the diode are located on the "mixed board".  
The timing does not match the patent (column 5, lines 53-65). It is not clear whether this is an issue of this
particular machine, a difference between different generations of Mathatronics calculcators, or simply incorrect data in
the patent. The wheel advances by one character (1/20th of a full turn) every 5ms (instead of the 2.5ms claimed in the
patent).



The sensor is an inductive sensor triggered by a magnet in the character wheel. The sensor produces a pulse of roughly
300mV on a timescale of a few milliseconds when the magnet passes the sensor at the speed produced by the motor. One end
of it is connected to ground through a separate wire, connected to ground at the logic unit[^1]. The other end is
connected directly to the base of a transistor in the logic unit, see [here](./printer-logic.md).

[^1]: Presumably to avoid IR drop along the logic supply connection from drowning out the weak signal.
